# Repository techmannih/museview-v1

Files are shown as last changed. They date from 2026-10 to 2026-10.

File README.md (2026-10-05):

# MuseView V1

MuseView V1 is a compact Wi-Fi camera controller powered by standard **5 V USB-C**. It connects an **Arducam M0031 OV2640 camera** to an **ESP32-S3-WROOM-1-N16R8**, with dedicated camera power supplies, USB programming, an ASK/CAPTURE button and a status LED on a 50 × 35 mm board.

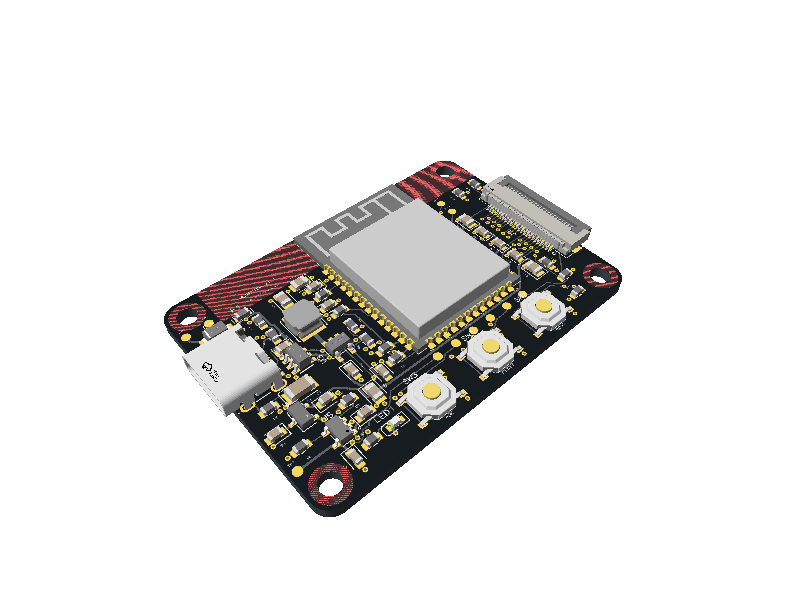
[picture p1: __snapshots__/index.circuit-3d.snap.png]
Assembled MuseView PCB


## Overview

MuseView brings the camera interface, power regulation and controls onto one board. The ESP32 module provides Wi-Fi, 16 MB flash for firmware and 8 MB PSRAM for camera buffers. The external M0031 camera connects through the 24-pin FPC connector on the right edge; the USB-C connector on the left supplies power and provides a programming/debug connection. All PCB assembly components are on the top side.

The included ESP-IDF firmware provides a local photo-capture page. A phone or computer joins the board's Wi-Fi network and opens the page in a browser. Photos can be taken from that page or with the physical ASK button, making the board a starting point for embedded camera projects and image-capture applications.

## How it works

1. **Power the board.** USB-C supplies 5 V through the input protection circuit. The regulators generate the shared 3.192 V MCU/camera I/O supply, 2.8 V camera analog supply and 1.296 V camera core supply.
2. **Initialize the camera.** After startup, the ESP32 releases the camera's power-down/reset controls, configures the OV2640 and receives image data over its 8-bit DVP interface. The supplied firmware captures JPEG images at SVGA resolution using PSRAM-backed camera buffers.
3. **Connect over Wi-Fi.** With the firmware flashed, join `MuseView-XXXXXX` using the configured Wi-Fi password, then open `http://192.168.4.1/`. The ESP32 serves the capture page directly to the connected device.
4. **Take a photo.** Click **Capture** in the browser or press **ASK/CAPTURE** on the board. The LED lights during capture. **Last ASK capture** displays the most recently cached image; the latest JPEG is kept in RAM and replaced by the next capture. Images stay on the local connection and are not stored permanently.
5. **Program or recover.** USB supports firmware flashing and serial debugging. RESET restarts the board; holding BOOT while pressing RESET enters the ESP32 ROM download mode.

See the [firmware setup guide](https://github.com/techmannih/museview-v1/blob/main/firmware/README.md) for Wi-Fi configuration, flashing and the browser interface.

## Use

```sh
bun install --frozen-lockfile
bun run verify
bun run dev
bun run build:preview
bun run build:handoff
bun run export:assembly
bun run snapshot
bun run snapshot:3d
bun run export:release
```

The library/CLI is pinned to tscircuit 0.0.2687. Builds use selected supplier numbers, not automatic part substitution. `hardware-contract.json` is checked against the generated source netlist. `scripts/check-decoupling.mjs` measures actual local copper. The strict `bun run check:schematic-style` gate runs Style Analysis 0.0.39 on all four built sheets and fails on any issue; the native CLI placement command only prints suggestions. Its dependencies are isolated while explicit pins preserve the existing PCB runtime. Placement, routing diagnostics and a separate Gerber copper short check must pass before a release can be considered.

Start the viewer with `bun run dev` (optionally `--port 3020`) after installing the locked dependencies. The launcher requires the local pinned CLI and refuses a missing or mismatched installation. A bare global `tsci dev` can load a different browser renderer and produce a stale-routing error followed by disconnected-port errors; see [viewer troubleshooting](https://github.com/techmannih/museview-v1/blob/main/docs/routing.md#viewer-troubleshooting). The separately published website renderer is supported for its reviewed mounting-keepout representation; it still rejects other stale routing inputs.

## Design

- 50 × 35 mm, 1.6 mm FR4, four copper layers, black solder mask, **all 49 fitted components on top; no bottom assembly**.
- Via minima: **0.30 mm hole / 0.45 mm pad**. Actual through vias: **0.30 mm drill / 0.60 mm pad**, with 0.15 mm annular rings.
- L1 components/signals, L2 ground reference, L3 common MCU/camera I/O power, L4 signals. Antenna keepout on all copper layers.
- USB-C USB 2.0 device: independent 5.1 kΩ CC pull-downs, USBLC6-2SC6, 33 Ω data resistors, 750 mA PTC, SMF5.0A input TVS.
- TLV62569: **3.192 V nominal** shared ESP32/camera I/O, using 432 kΩ/100 kΩ, both **0.1%**.
- XC6206P282MR: camera analog 2.8 V, supplied from protected USB 5 V to avoid marginal dropout headroom.
- SGM2059: camera core **1.296 V nominal**, using 25.5 kΩ/40.2 kΩ, both 1%. Net: **CAM_1V3**, TP7 acceptance **1.24–1.36 V**.
- Native USB ROM recovery, UART0/JTAG pads, BOOT, RESET, ASK GPIO16 and LED GPIO17.
- Camera RESET GPIO18 defaults low and PWDN GPIO8 defaults high. Firmware must actively release them.

These rail choices retain the corrected 1.296 V camera core and avoid a marginal 2.8 V camera-to-3.318 V ESP32 I/O interface. See [electrical decisions](https://github.com/techmannih/museview-v1/blob/main/docs/electrical-review.md) and the [pin contract](https://github.com/techmannih/museview-v1/blob/main/hardware-contract.json).

## Repository

The repository contains the MuseView board entrypoint, local component and CAD imports, a Bun lockfile, automated checks and schematic/PCB/3D snapshots.

```text
index.circuit.tsx             board, four schematic sheets, placement and copper
pcb-routes.json               reviewed routes, guarded by geometry/net fingerprint
routing/                     native geometry and pinned routing-generation inputs
imports/                     JLC-imported ICs/connectors/CAD; native passives
scripts/                     verification, mutation tests and exports
sourcing/                    timestamped JLCSearch evidence and alternatives
__snapshots__/               reviewed schematic, PCB and 3D renders
docs/                        assembly, electrical review, bring-up, release checks
firmware/                    matching ESP-IDF camera bring-up application
.github/workflows/           automated build/check pipeline
dist/                        generated CAD/manufacturing output (ignored)
release/                     published, versioned handoff files
```

USB-C is on the left, the camera connector is on the right, the antenna faces the top edge, and ASK / RESET / BOOT sit along the bottom edge. Bottom copper carries routing; all fitted components are on top.

## Assembly boundary

The external Arducam M0031 camera, USB cable and enclosure are not JLCPCB assembly components. JLCSearch quantities are cached catalogue evidence, not reserved stock or a confirmed assembly quotation. Recheck the selected BOM in JLC's assembly portal immediately before ordering. FPC mating, prototype rail/transient measurements, USB signal integrity and camera capture require hardware validation; successful software checks do not establish those results.

Component import/stock provenance and datasheets: [sources](https://github.com/techmannih/museview-v1/blob/main/docs/sources.md). Current validation and open physical checks: [release checks](https://github.com/techmannih/museview-v1/blob/main/docs/release-checks.md).

View the four schematic sheets: [USB](https://github.com/techmannih/museview-v1/blob/main/release/schematic-usb.svg), [power](https://github.com/techmannih/museview-v1/blob/main/release/schematic-power.svg), [MCU](https://github.com/techmannih/museview-v1/blob/main/release/schematic-mcu.svg), [camera](https://github.com/techmannih/museview-v1/blob/main/release/schematic-camera.svg). Board views: [top](https://github.com/techmannih/museview-v1/blob/main/release/pcb-top.svg), [bottom](https://github.com/techmannih/museview-v1/blob/main/release/pcb-bottom.svg). Editable manufacturing/CAD exports: [Gerbers](https://github.com/techmannih/museview-v1/blob/main/release/museview-v1-gerbers.zip), [KiCad](https://github.com/techmannih/museview-v1/blob/main/release/museview-v1-kicad.zip), [STEP ZIP](https://github.com/techmannih/museview-v1/blob/main/release/museview-v1-step.zip), [GLB](https://github.com/techmannih/museview-v1/blob/main/release/museview-v1.glb). See [routing workflow](https://github.com/techmannih/museview-v1/blob/main/docs/routing.md) before changing placement or nets.

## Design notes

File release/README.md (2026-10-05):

# MuseView V1 manufacturing handoff

**ORDER HOLD:** this package corrects the camera core to CAM_1V3, 1.296 V nominal (R8 25.5 kΩ / R9 40.2 kΩ). The previous 1.197 V package is superseded. Exact M0031 flex qualification and physical bring-up remain open; see `../docs/camera-mating.md`.

- `museview-v1-gerbers.zip`: four copper layers, solder masks/paste, silkscreen, outline, plated L1–L4 drills (all vias 0.30 mm drill / 0.60 mm pad) and nonplated drills. Generic exporter BOM/CPL are removed to avoid competing assembly files.
- `jlc-bom.csv` and `jlc-cpl.csv`: the authoritative 49-component **top-only** assembly pair. No bottom-side components. Board-center origin matches the Gerbers. Validate polarized-part rotations in JLC's placement preview.
- `schematic-usb.svg`, `schematic-power.svg`, `schematic-mcu.svg`, `schematic-camera.svg`: four readable vector schematic sheets.
- `pcb-top.svg`, `pcb-bottom.svg`, `pcb-top.png`: copper/placement views.
- `museview-v1-kicad.zip`: PCB, project, root plus four schematic sheets and 16 model files. Extract the whole archive; retain its `3dmodels/` tree.
- `museview-v1-step.zip` (extract `museview-v1.step`), `museview-v1.glb`, `3d.png`: assembled mechanical model, portable textured 3D model and preview. Camera is an external assembly item. The STEP is zipped because the cloud importer exceeds its 32 MiB RPC limit when copying the loose assembled model; component STEP/OBJ files are retained for rendering.
- `circuit.json`: exact verified tscircuit interchange/netlist/geometry; CAD URLs resolve relative to repository root.
- `camera-supply.json`: divider identities, tolerances, calculated DC/temperature bounds and 1.24–1.36 V limits.
- `verification.json`, `sha256.json`: verification evidence and artifact checksums.

J1 uses the supplied USB-C CAD origin correction: local Y = -2.3500289000000517 mm. The browser preview, GLB, KiCad model offset and assembled STEP all use this origin. The pinned STEP exporter otherwise recentres the model and ignores its explicit origin, so `scripts/align-usb-step.mjs` corrects only J1's mapped placement after export; handoff validation checks that placement. The footprint, BOM/CPL and routed copper are unchanged.

USB-C is 5 V only. Use the assembly, electrical review and bring-up documents in `../docs/`. Physical power/startup/USB/camera tests and manufacturer stackup/impedance review remain open. This package is an engineering prototype handoff, not a claim of measured production qualification.

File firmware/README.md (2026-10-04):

# Hardware bring-up firmware

ESP-IDF 5.4.x, target ESP32-S3, espressif/esp32-camera 2.1.8. Uses octal 8 MB PSRAM and 16 MB flash. The pin header is generated from `hardware-contract.json` by `bun run generate:firmware-pins`; the verification task rejects stale mappings.

```sh
cd firmware
idf.py set-target esp32s3
idf.py menuconfig
idf.py build
idf.py -p YOUR_PORT flash monitor
```

Set a unique local Wi-Fi password in the MuseView menu (at least 8 characters). After flashing, connect a phone to `MuseView-XXXXXX` using that password; the development default is `museview-setup`. Open http://192.168.4.1/ to capture a JPEG. ASK captures a fresh frame and updates the last-image endpoint; LED lights during capture. No camera image is sent to an external service. This AP is a bring-up interface, not production provisioning or an Internet API.

The application checks PSRAM, initializes the OV2640 in JPEG SVGA mode, and serializes camera access between HTTP and the debounced ASK task. Captured frames are copied to PSRAM-backed memory before returning the driver's frame buffer. HTTP returns an error when no frame is available. Maximum cached JPEG is 1 MiB. There is no SD card or persistent image storage.

Native USB ROM recovery remains available by holding BOOT during RESET. This firmware provides USB Serial/JTAG console, not UVC webcam firmware. Electrical operation and images are untested until the physical board is assembled.

The corrected camera core is CAM_1V3, 1.296 V nominal from the hardware divider. The generated header carries a 1296 mV target and 1240–1360 mV acceptance limits; the boot log reports these as external measurement requirements. There is no ADC connection to this rail, so firmware neither programs nor validates its voltage. GPIO assignments remain unchanged.

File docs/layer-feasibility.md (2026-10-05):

# Two-layer feasibility review — 2026-10-05

**Decision: retain the existing four-layer release. The tested two-layer draft is NOT READY and must not be ordered. Four layers are recommended, not mandatory for an ESP32-S3 design.**

Espressif's [PCB layout guidelines](https://docs.espressif.com/projects/esp-hardware-design-guidelines/en/latest/esp32s3/pcb-layout-design.html) explicitly permit two layers, while recommending four. They call for minimal bottom-layer routing and continuous ground in a two-layer implementation, and a continuous reference beneath USB differential routing. MuseView uses the WROOM module; bare-chip RF, crystal and memory layout requirements must not all be interpreted as baseboard requirements.

## What was tested

The isolated trial started from commit `7c9b41137d943b7360f18bac38ae7db58a59127b`. It retained the 50 × 35 mm outline, existing assembly-part positions, top-only assembly, USB-C 5 V without PD, ESP32-S3-WROOM-1-N16R8, M0031 and the existing supply targets. The declared via minima remained 0.30 mm drill / 0.45 mm pad; actual vias retained 0.30 mm drills / 0.60 mm pads.

The trial removed the inner planes, routed supply connections on the outer layers, added top/bottom GND pours and additional ground stitches, and tried several route orders and local ground connections. It was a real two-layer routing experiment, not merely a change to the board's layer count. Existing release checks were not disabled to accept it.

## Result

| Check | Latest trial result |
| --- | --- |
| Board copper layers | 2 |
| Grid-router failed connections | 0; 120 generated traces |
| Complete circuit geometry | 169 PCB traces, 143 vias |
| Native circuit build | Failed: 23 `pcb_port_not_connected_error` diagnostics on GND |
| Independent ground-polygon analysis | Three disconnected ground groups |
| Manufacturing export | Not performed; draft rejected before release |

The ground groups are the main board ground, a separate island containing **C13.pin2 and C16.pin2**, and another containing **J2.DGND**. The 23 diagnostics are not 23 separate islands: the checker reports multiple members of the incompletely connected net. Zero router failures therefore does not establish complete PCB connectivity.

A second diagnostic sampled USB centerlines at intervals no greater than 0.05 mm against opposite-layer GND pours and pads. It found uncovered runs up to approximately **3.69 mm on the D− port/ESD network** and **2.96 mm on D+**. This includes connector and IC escapes. It is a geometric reference-coverage check, not an impedance calculation or a physical USB test. PORT/ESD aliases refer to the same connected copper and must not be summed as independent measurements. Ground traces and vias are not counted as a reference plane by this diagnostic.

The machine-readable [trial evidence](evidence/two-layer-feasibility.json) records the draft hashes, diagnostics, ground groups and sampling results. The rejected draft and its detailed logs are retained separately in the local feasibility workspace; they are not release inputs.

## Consequence

This experiment does not prove that a two-layer MuseView is impossible. It shows that the tested conversion of the current placement does not meet connectivity and return-path requirements. A two-layer version needs further placement/routing work around the camera grounds, power distribution and USB, followed by complete verification and new manufacturing exports. A smaller layer count alone is not a safe cost reduction.

The committed PCB, routing, BOM/CPL, Gerbers and CAD remain the existing four-layer design. Its inner GND and VDD_IO planes are electrically active and cannot simply be deleted. The existing M0031/AFC01 mechanical qualification and JLC placement-preview items remain open; this layer review does not close them or authorize an order.

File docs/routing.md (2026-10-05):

# Routing and reproducibility

V1.1 uses a 50 × 35 mm outline. The source circuit, local bypasses, FPC fanout, copper planes and RF exclusion are defined in `index.circuit.tsx`. All assembly is on top. Signal routing uses the two outer copper layers; L2 is GND and L3 is VDD_IO.

The remaining copper is generated by `scripts/route-grid.py` on a 0.05 mm grid from tscircuit's exported geometry. USB data contacts escape under the receptacle; active ESP32 signal pads escape toward the free area under the module. Local ground and I/O supply spurs terminate directly on their planes. All fixed and generated vias use 0.30 mm drills and 0.60 mm copper pads (0.15 mm annular rings). The board declares `minViaHoleDiameter={0.3}` and `minViaPadDiameter={0.45}`. The pad minimum is a lower bound; `pcbStyle` and the explicit vias retain actual 0.60 mm pads. The generator reads the captured minima and selects a pad of at least drill + 0.30 mm, preserving the 0.15 mm annular ring and reserving its full clearance. Feedback traces are routed before plane drops, with JTAG_TDO routed after the camera bus to keep the larger via escapes clear. C4's ground via is at (-13, 10.1) mm to clear its pad and the antenna exclusion. The router checks expanded pad, fixed-track, via, hole, RF and board-edge obstacles, then joins each remaining net.

`routing/input.simple-route.json` is the exact native routing input. `routing/geometry.json` contains the source/port/placement records needed by this board-specific generator, including the explicit USB ESD bypass and 39 fixed vias. These are regeneration inputs, not manufacturing files. Python 3.11+ and the pinned NumPy package in `routing/requirements.txt` are needed only to regenerate routing. Bun builds replay the checked copper without Python.

```sh
python3 -m venv .venv
.venv/bin/pip install -r routing/requirements.txt
bun run capture:routing
PYTHON=.venv/bin/python bun run regenerate:routing
bun run verify
```

The generator refuses to replace `pcb-routes.json` if any connection fails. `scripts/board-router.ts` then replays that copper only when the geometry/net fingerprint matches the current tscircuit input. Native DRC, exact endpoint checks and the separate Gerber short analysis still run. GitHub CI regenerates the copper, checks that the saved file matches, and runs the full verification suite.

When changing electrical values, nets or placement, run `bun run capture:routing` to capture native prerouting geometry from the current JSX source. This uses an empty capture-only router and never exports that unrouted intermediate as manufacturing output. Regenerate the grid copper and run the full verification suite next. The fingerprint now includes the hardware contract, so divider-value or power-net changes also invalidate replay even if physical coordinates are unchanged. Ordinary schematic display-text edits remain excluded. Never copy a fingerprint onto stale routes.

After verification, update and compare the 2D and 3D snapshots and run `bun run export:release`. All exported drills are through plated L1–L4 or nonplated. There are no blind/buried drills. The bottom stencil is intentionally empty; bottom copper is routing, with no fitted components. Recheck JLC rotations, stackup and physical USB/camera operation before production.

The snapshot tool's optional selector route-cache writer may warn that a via selector is ambiguous. That secondary cache is not used; the explicit geometry-guarded route file supplies the copper.

## Viewer troubleshooting

The 2026-10-04 report of 137 errors came from a checkout without local dependencies, running global tscircuit 0.0.2308. Its browser renderer rejected the saved routing fingerprint; the 134 disconnected ports and two missing traces followed from that rejection. Use the locked tscircuit 0.0.2687 installation with `bun run dev`, stop the old server, and reload the browser. The launcher now checks the installed version before starting the local CLI. Do not remove the fingerprint guard or copy an expected hash over stale copper.

The pinned viewer also runs supplier orientation analysis. This exposed D1's unused pin-label map: native numbering put the anode at pin 1, while C193402 numbers the cathode as pin 1. The import now explicitly maps pin 1/cathode to the west VBUS_5V pad and pin 2/anode to the east GND pad. The electrical contract and a regression test enforce this. The TVS symbol is imported from `imports/SMF5_0A/TVSSymbol.tsx`, with explicit cathode/anode ports and drawing paths. Its upper cathode bar connects to VBUS_5V; its lower anode connects to GND. Native routing inputs and route endpoints were regenerated for the corrected port identities; physical pad positions, net geometry, component rotations and copper paths are unchanged. JLC's actual assembly placement preview remains pending.

### Missing TVS symbol

The published v0.1.11 viewer displayed `Symbol not found: avalanche_diode_sm_up`, although the pinned local renderer could draw it and the cloud build passed. Build success did not establish viewer symbol compatibility. D1 now imports a self-contained unidirectional TVS symbol instead of requesting that catalog entry. The drawing, labels and numbered ports are included in circuit JSON, keeping C193402 pin 1 as the cathode. This is a schematic-only change.

`bun run check:schematic-render` renders every sheet, rejects missing-symbol diagnostics and verifies the embedded TVS cathode bar, triangle and both leads. It runs in verification and release export; regression tests also reject reverting D1 to the catalog-only symbol. The published viewer must still be inspected after deployment because its renderer is versioned independently.

### Published tscircuit.com renderer

The hosted compatibility capture was repeated on 2026-10-05 after the 0.30 mm via reroute. Its complete routing-input fingerprint is `904ff28e-139073e2-1060756`, versus the pinned input `c6bc715a-6984f1ee-1060756`. Capturing the same source with tscircuit 0.0.2744 / core 0.0.2079 showed exactly four changes: obstacles 257–260 use `type: rect` instead of `type: oval`. These are the four unconnected, all-layer mounting-hole keepouts, each 4.6 × 4.6 mm at (±22.25, ±14.75). Core 0.0.2021 emitted ovals; the newer core emits their bounding rectangles.

The grid router uses these rectangular bounds. Both runtime captures describe the same current placement, nets and regenerated copper. `board-router.ts` accepts this one reviewed **complete input fingerprint**, only when the saved routing still has its corresponding original fingerprint. No shapes, dimensions, nets or other fields are removed from fingerprinting. Every other input continues to fail closed. The added replay tests check identical returned copper for both captures and rejection of moved/resized keepouts, changed layers, changed pad shapes and changed nets.

This compatibility entry is specific to this routing revision. A future renderer or design change needs a fresh capture, full input comparison and verification; do not add its hash merely to dismiss the error. Use the pinned release pipeline for fabrication exports. Website edits must also be saved/published: pushing GitHub alone does not update a separately published registry release.

### Cloud sandbox file-size failure

Release v0.1.5 failed before circuit compilation while copying repository files into the cloud sandbox. The [build log](https://tscircuit.com/techmannih/museview/releases/a095f8d4-827e-4740-89f3-d1a58d011f7a) reports a 46,622,166-byte serialized RPC payload against a 32 MiB limit. The next input after the successfully copied GLB was the 23,312,026-byte assembled `release/museview-v1.step`.

The assembled model is now distributed as `release/museview-v1-step.zip`; extracting it restores the full STEP. The [GitHub importer filter](https://github.com/tscircuit/api.tscircuit.com/blob/01251be3e667f5f4b03e488bc4ed214bf7caec4f/lib/github/file-filter.ts) skips ZIP files, so the large handoff artifact is not a cloud build input. Individual component STEP/OBJ assets under `imports/` remain in the package. `export:release` generates the loose assembled STEP under ignored `dist/release/` before packaging it; `check-handoff.mjs` validates the archive and rejects loose release STEP files.

`ignoredFiles: ["release/**", ...]` also prevents generated handoff files from entering the local dev file server. This setting alone does not fix GitHub cloud imports, which use their own fixed filter. A new GitHub sync/release is needed; retrying the already-copied v0.1.5 file set will repeat the failure. No electrical, routing, schematic or 3D geometry changes are part of this packaging fix.

## Layer review, 2026-10-05

Four layers are retained for this revision. The inner layers are active: the regenerated routing includes 25 top-to-GND-plane and 16 top-to-VDD_IO-plane transitions, in addition to explicitly placed bypass/ground vias. All 176 via barrels span L1–L4; a route transition to an inner plane does not denote a blind via. The outer signal routing includes 841 bottom-layer wire points. Removing the inner copper would disconnect the current power/ground distribution and change its return paths.

A two-layer ESP32-S3 design is possible in principle. Espressif's [PCB layout guidelines](https://docs.espressif.com/projects/esp-hardware-design-guidelines/en/latest/esp32s3/pcb-layout-design.html) recommend four layers, and describe two layers with minimal bottom routing and a continuous ground plane. This board uses a WROOM module, so chip-level RF layout rules are not all baseboard requirements. The present dense baseboard does use its planes; a two-layer version needs rerouted power, a reviewed ground pour and USB return paths. No two-layer layout has been qualified in this revision. This assessment preserves the existing 50 × 35 mm component placement rather than claiming four layers are mandatory for every implementation.

An [isolated two-layer routing trial](layer-feasibility.md) subsequently completed the generated routes but failed native ground connectivity checks. Polygon analysis found separate C13/C16 and J2.DGND ground islands, and USB reference-coverage sampling found gaps. That draft was rejected before manufacturing export; the four-layer source and release artifacts remain unchanged.

J1 now uses tscircuit's native `standard="usb_c"` schematic, with grouped VBUS/CC/data/GND pins and S1–S4 shield tabs below. Supplier pad numbering is retained: pins 7/9 are D− and 8/10 are D+. The contract rejects changes to that mapping. Its exact footprint and user-supplied CAD alignment are unchanged.

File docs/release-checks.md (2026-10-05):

# Release checks

Status: **NOT READY** for the first prototype. Only the two pre-order items below remain open; post-assembly measurements are listed separately. The machine-readable [`verification.json`](../release/verification.json) records the exact circuit hash and check outcomes. Manufacturing exports are versioned in `release/`, with SHA-256 hashes.

Local verification completed on 2026-10-05: source netlist, schematic placement, strict all-sheet Style Analysis, PCB placement, routing difficulty, board build, electrical contract, actual copper continuity, local bypasses, exact M0031 supply bounds, assembly/stock checks and separate Gerber short analysis passed. Twenty-nine regression tests passed, including supplier TVS pin polarity, the two captured renderer inputs and rejection of schematic style regressions. Native 2D and 3D snapshot regeneration/compare runs matched. The GitHub workflow repeats the circuit checks and 2D snapshots and compiles the matching ESP-IDF 5.4.2 firmware.

The 0.30 mm drill / 0.60 mm via pad revision includes regenerated routing, a native standard USB-C schematic and exact supplier pin-mapping checks. Four active copper layers are retained; see `routing.md` for the layer assessment. D1 imports the self-contained TVS drawing with its cathode bar toward VBUS_5V. All four sheets pass the pinned Style Analysis and missing-symbol rendering checks. No issue filters or disabled checks are used. The current routing fingerprint and drill tools are recorded in `release/verification.json`.

Exact trace/via counts are recorded in `verification.json`. There are zero build/routing errors and zero detected Gerber shorts. The retained native width warnings are explained in `electrical-review.md`; critical local widths are checked against their exact endpoints. All 28 selected assembly part numbers had positive JLCSearch stock in the dated evidence. This is availability evidence, not a PCBA order acceptance.

The handoff exporter verifies five KiCad schematic files (root plus four children) and all 16 distinct native/imported STEP models. GLB embeds the local OBJ bodies. KiCad files are interchange exports; no native KiCad ERC/DRC run is claimed. The tscircuit source and its checked copper remain authoritative.

| Check | Evidence required |
|---|---|
| Electrical contract | `bun run check:contract`, matches generated netlist |
| Stock | `sourcing/bom-with-stock.csv`, timestamped JLCSearch URLs |
| Type and source netlist | `bun run typecheck`, `tsci check netlist` |
| Placement and schematic | Native checks, strict `check:schematic-style` with zero issues, plus reviewed four-sheet renders |
| PCB | Zero build errors, connectivity checks, zero Gerber shorts |
| Bypass loops | `bun run check:decoupling`, actual local copper length |
| Assembly | Exact part identities, all fitted parts top, FPC pitch, JLC placement review |
| Firmware | CI compile and generated pin header consistency; physical operation separately |
| Fabrication | Review Gerber/drill/stackup/impedance with manufacturer |
| Hardware | Rails, startup, thermal/current/USB/camera tests in `bring-up.md` |

First-prototype blockers:

1. **Exact M0031-to-J2 mating qualification** — AFC01 requires a tighter 0.29–0.31 mm tail than F32R’s 0.27–0.33 mm range. Exact seating/latch fit remains unqualified. The numbered-tail photo also raises a possible reversed camera-to-J2 mapping after accounting for contact face and insertion direction; the current one-to-one numbering is not physically signed off. See `camera-mating.md`.
2. **JLC assembly placement approval** — the exported rotations are CAD angles. Verify U1/J1/J2/D1/LED1/U2/U3/U4/U5 alignment and centroids in the authenticated JLC preview, using `placement-review.md` and the generated `release/placement-review.json`. The Gerber upload was recognized as 4 layers, 50 × 35 mm. No order/payment was submitted.

After assembly: no physical PCB has been tested in this task. Source-current/inrush, rails/ripple/thermal behavior, USB enumeration and camera capture are prototype bring-up work before production. They are not circular prerequisites for ordering the first prototype. Manufacturing stackup and assembly eligibility must still match the actual quote; automated checks do not replace manufacturer review.

The 1.197 V camera-core revision is superseded. R8 = 25.5 kΩ and CAM_1V3 are mandatory. Electrical checks validate the declared board nets, including J2 pin 10 to CAM_1V3; they cannot prove the camera-to-connector contact mapping. See `camera-mating.md` for the tolerance comparison and possible numbering reversal. Neither exact tail qualification nor the numbered physical mating has been signed off.

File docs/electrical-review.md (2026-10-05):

# Electrical decisions

## Standard USB-C

The final user clarification specifies standard 5 V USB-C, overriding the initial request for PD. J1 CC1 and CC2 each have their own 5.1 kΩ resistor to ground. There is no controller or higher-voltage negotiation. Both receptacle D+ contacts and both D− contacts are connected for reversible insertion. USBLC6's physical 1/6 and 3/4 pass-through pairs are represented as internally connected pins. GPIO19 is D− and GPIO20 D+.

A 750 mA resettable fuse is a thermal protective element, not an accurate current limiter. The board has no CC-current measurement or programmable input-current limit. Use a regulated 5 V source rated at least 1 A for bring-up. Compatibility with every USB host's pre-enumeration current budget and inrush limit is **not established**. Do not label the product USB-IF certified. The 5 V TVS provides transient suppression; it cannot protect the 5.5 V-maximum buck against sustained overvoltage.

## Voltage domains

The exact Arducam M0031 product specifies a 1.3 V ±5% core supply. OmniVision OV2640 datasheet v2.2, table 6, narrows this to 1.24–1.36 V. The earlier v1.6-based 1.197 V design was incorrect for this module and is superseded. The selected SGM2059 divider is now R8 = 25.5 kΩ (C22920, 0603WAF2552T5E) and R9 = 40.2 kΩ (C2933218, FRC0603F4022TS), both 0603, 1%, 100 ppm/°C. Exact JLCSearch identities and positive quantities were refreshed on 2026-10-04. The implementation uses:

| Rail | Equation | Nominal | DC tolerance estimate |
|---|---|---:|---:|
| MCU + camera DOVDD | 0.600 × (1 + 432k / 100k) | 3.192 V | 3.123–3.261 V, VFB ±2%, resistors ±0.1% |
| Camera DVDD | 0.793 × (1 + 25.5k / 40.2k) | 1.296 V | 1.254–1.339 V, VFB 0.773–0.813 V, resistors ±1% |
| Camera AVDD | XC6206P282MR | 2.800 V | ±2% initial, before line/load/temp effects |

The camera divider produces 1.296022 V nominal. Using the SGM2059 full-temperature feedback limits 0.773–0.813 V and initial 1% resistor tolerances gives 1.253626–1.339127 V. Including independent worst-direction 100 ppm/°C drift over the sensor DC table’s −30 to +70°C range (55°C maximum excursion from 25°C) gives 1.248367–1.344948 V. This leaves approximately 8.37 mV of lower-bound and 15.05 mV of upper-bound margin before ripple, transients and measurement uncertainty. `check:camera-supply` computes these bounds from actual generated resistor values and exact stocked-part metadata. These temperature assumptions are a calculation boundary, not an assembled-board operating-temperature rating.

The first two ranges are worst-case DC divider calculations, **not measured regulation guarantees** including ripple and transient droop. Both R6 and R7 need 0.1% tolerance; substituting the original 1% feedback parts defeats the I/O voltage margin. Camera SDA/SCL pull-ups, reset/power-down control and pixel data use the same nominal rail as the ESP32. Confirm actual sensor VOH/VIH and output loading on the purchased M0031 revision.

U4's input is the protected 5 V rail. A 3.192 V input would leave too little worst-case dropout margin at 2.8 V. At 50 mA analog load U4 dissipates approximately (5−2.8) × 0.05 = 0.11 W. U5 is fed from VDD_IO; at 100 mA it dissipates approximately 0.19 W. These are load scenarios, not measured loads. Verify thermals and camera rail current; there is no established full-temperature operating rating for this assembled board.

## Reset and startup

ESP EN uses 10 kΩ and 1 µF. Camera RESET is held low by 10 kΩ, while PWDN is held high by 10 kΩ. Firmware first drives those states, waits for rails, then releases PWDN and RESET before driver initialization. This does not independently enforce the sensor's rail sequencing; verify rail rise/fall waveforms against the exact sensor specification, especially on unplug/replug. GPIO0 retains a BOOT pull-up; GPIO35/36/37 are reserved for octal PSRAM and unused.

## Local routing

Critical regulator input capacitors and the ESP32 HF capacitor have explicit top copper and nearby ground vias. Scripts verify actual lengths: regulator/MCU supply bypass ≤3 mm, USB ESD supply bypass 3.774 mm (≤4 mm) and local capacitor-to-ground-via ≤1.6 mm. The TLV62569 switch connection is ≤3 mm. Camera C13/C14 supply bypasses are each about 4.70 mm (both top-only, no vias); regression checks enforce 5.1 mm maximum and those via budgets. C15 and J2 DOVDD have ≤1.6 mm local spurs to the common inner I/O plane. The library's generic capacitor limit applies to arbitrary power-net branches; `imports/passives.tsx` therefore sets a distribution-branch limit while the stricter local checks operate on the actual intended endpoints.

Four-layer pours preserve the ground reference and antenna exclusion. Fabricator stackup, dielectric thickness, USB differential impedance/skew and return continuity must be reviewed with the exported copper; a nominal track width alone does not establish 90 Ω differential impedance. The board runs ESP32-S3 USB full speed, not high speed. Camera XCLK/PCLK edge quality and timing must be measured with the selected flex cable.

## Scope

The firmware supports camera capture and hardware bring-up. Physical validation covers the power rails, startup behavior, USB operation and camera interface; see `bring-up.md` for the measurement procedure.

The pinned native trace-width checker emits net-wide width warnings because it compares each requested local trace width with every branch on the same electrical net. The dedicated endpoint/width/length checks independently enforce the critical local widths, including 0.2 mm post-ESD USB segments (the connector fanout is 0.15 mm); these warnings are retained in the exported circuit JSON. No routing, connectivity, placement or Gerber short error is waived.

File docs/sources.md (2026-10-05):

# Component sources and datasheets

Checked 2026-10-04. JLC evidence includes exact fetch timestamps and URLs in `sourcing/stock-snapshot.json`. Stock is a cached search snapshot, not a reserved quantity.

- ESP32 module: https://documentation.espressif.com/esp32-s3-wroom-1_wroom-1u_datasheet_en.pdf
- ESP32 hardware guidance: https://docs.espressif.com/projects/esp-hardware-design-guidelines/en/latest/esp32s3/pcb-layout-design.html
- TLV62569: https://www.ti.com/lit/ds/symlink/tlv62569.pdf
- XC6206: https://product.torexsemi.com/system/files/series/xc6206.pdf
- SGM2059: https://www.sg-micro.com/rect/assets/c90e4805-a9a9-4001-be72-fb96737d867e/SGM2059.pdf
- USBLC6-2: https://www.st.com/resource/en/datasheet/usblc6-2.pdf
- OV2640 manufacturer datasheet v2.2, table 6, hosted by Robu: https://robu.in/wp-content/uploads/2024/09/OV2640_DS.pdf
- Exact Arducam M0031 product/core/mating connector: https://www.arducam.com/arducam-ov2640-camera-module-2mp-mini-ccm-compact-camera-modules-compatible-with-arduino_m0031esp32-esp8266-development-board-with-dvp-24-pin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
- Amphenol F32R recommended mate: https://www.amphenol-cs.com/product/f32r1a7h111024.html
- Amphenol F32R bottom-contact/0.30 mm interface: https://cdn.amphenol-cs.com/media/wysiwyg/files/documentation/datasheet/flex/ffc_fpc_050mm_f32r_f32q.pdf
- Amphenol F32R/F32J dimensioned drawing A-S0201 rev C, visually inspected: https://cdn.amphenol-cs.com/media/wysiwyg/files/drawing/f32r-f32j.pdf (SHA-256 `ccb80cfe928b3ab5cb602e74da5e3fe788bbf19c41fc63e2e992ffa461303bb0`)
- Amphenol F32R thickness tolerance, specification IS.EQC.001 rev D: https://cdn.amphenol-cs.com/media/wysiwyg/files/documentation/f31q-f32r-f52q-f52r_prodspec.pdf (manufacturer PDF downloaded via https://mm.digikey.com/Volume0/opasdata/d220001/medias/docus/6256/f31q-f32r-f52q-f52r_prodspec.pdf ; SHA-256 `c78407cb7ef80c4142c3566afae8f0222eef4fee88663f247b355b14d4eee4a7`)
- JUSHUO AFC01 drawing/specification, C262669: https://datasheet.lcsc.com/datasheet/pdf/97e3ba016a78286ffa6cfbc591e2beb6.pdf
- M0031/pinout: https://blog.arducam.com/ov2640-vs-ov7670-detailed-comparisons-and-resources/
- JLCSearch: https://jlcsearch.tscircuit.com/

Native resistors/capacitors use explicit JLC numbers rather than an automatic parts engine. Other parts and local STEP/OBJ bodies were obtained through tscircuit's JLC import flow. Supplier CAD/symbol data remain subject to their original terms; no blanket relicensing of vendor assets is asserted.

The power and interface design uses a common 3.192 V MCU/camera I/O supply, 1.296 V camera core, 0.1% main feedback resistors, 5 V analog-LDO input, controllable camera reset/powerdown, camera I/O decoupling and local ESD-supply bypass. USB-C supplies standard 5 V power.

Supplier STEP entity terminators were normalized from `) ;` to `);` for the pinned exporter’s parser. Geometry/entity arguments were not changed. `bun run normalize:step` reproduces this formatting operation after a fresh import. Assembled STEP export then completes without omitted-model warnings.

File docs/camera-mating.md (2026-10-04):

# Exact M0031 camera mating review

Reviewed 2026-10-04 against both manufacturer drawings and the user-supplied numbered-tail photograph. **NOT READY: nominal interface compatibility is supported, but full AFC01 equivalence and the camera-to-board numbering are not qualified.**

The [Arducam M0031 product page](https://www.arducam.com/arducam-ov2640-camera-module-2mp-mini-ccm-compact-camera-modules-compatible-with-arduino_m0031esp32-esp8266-development-board-with-dvp-24-pin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) explicitly names **F32R-1A7H1-11024** as its mating connector. It specifies a 24-contact goldenfinger interface and 21 × 12.5 × 5.85 mm overall module size. Overall module dimensions are not a dimensioned or toleranced tail drawing.

## Manufacturer drawing comparison

Sources: [Amphenol exact-part page](https://www.amphenol-cs.com/product/f32r1a7h111024.html), [Amphenol customer drawing A-S0201, revision C, 2019-01-28](https://cdn.amphenol-cs.com/media/wysiwyg/files/drawing/f32r-f32j.pdf), [Amphenol specification IS.EQC.001, revision D, page 1](https://cdn.amphenol-cs.com/media/wysiwyg/files/documentation/f31q-f32r-f52q-f52r_prodspec.pdf), and [JUSHUO AFC01 drawing, revision A, 2024-05-18, PDF page 2](https://datasheet.lcsc.com/datasheet/pdf/97e3ba016a78286ffa6cfbc591e2beb6.pdf). These were visually inspected; dimensions below refer to the recommended mating **FPC**, not the PCB solder lands.

| Mating feature | F32R-1A7H1-11024 | AFC01-S24FCA-00 / C262669 | Assessment |
|---|---|---|---|
| Positions / contact side | 24 / bottom | 24 / lower (F) | Match |
| Tail pitch | 0.50 ±0.03 mm | 0.50 ±0.03 mm | Match |
| Reinforced tail thickness | **0.30 ±0.03 mm** | **0.30 ±0.01 mm** | AFC01 accepts a narrower specified range |
| Tail width, 24 positions | 12.50 ±0.05 mm (W = P × (N+1)) | 12.50 ±0.05 mm | Match |
| First-to-last contact centre span | 11.50 ±0.05 mm (B) | 11.50 ±0.03 mm | AFC01 tolerance is tighter |
| FPC contact width | 0.35 ±0.03 mm | 0.35 ±0.03 mm | Match; do not use Amphenol's separate 0.30 mm FFC column |
| Exposed contact length | 3.00 mm minimum | 3.0 mm minimum | Same minimum |
| Reinforced length callout | 6.00 mm reference | 6.0 mm | Similar nominal geometry; not an exact M0031 measurement |
| Lead-in corner callout | Two R0.30, FPC only | R0.20 | Different; no measured M0031 corner profile |
| Actuator | Push/pull slider | Flip latch, illustrated open at 90° | Different actuation and retention geometry |

The F32R accepts 0.27–0.33 mm tail thickness, while the AFC01 drawing recommends 0.29–0.31 mm. A tail satisfying F32R's limits can fall outside AFC01's limits. This **does not prove that the actual M0031 is incompatible**; it proves that the named-mate evidence alone does not guarantee AFC01 compatibility. The centre-span tolerance also narrows from ±0.05 to ±0.03 mm.

Both drawings require at least 3 mm exposed contact length. That is not a universal 3 mm insertion-depth instruction: the internal contact/stop/actuator datums differ. Do not interpret unrelated housing dimensions or a photograph's pixels as insertion depth. Full seating, contact overlap and latch retention still need an exact tail drawing or a fit record. The connectors are not PCB-footprint substitutes (for example, the 24-position body-width dimensions are 16.80 mm for F32R and 16.40 mm for AFC01).

## Numbering and insertion orientation

Current board facts from the imported footprint and released circuit: J2 is on **top**, rotated 90°, mouth facing east/right, signal solder row west of the body. Board pad 1 is at the south end, **(21.1999, −7.2498) mm**; pad 24 is north. For a bottom-contact connector, insert from east toward west with exposed contacts **down toward the PCB**. “Bottom contact” does not mean bottom-side component assembly.

The user's Screenshot 2026-10-04 at 18.29.46.png shows the tail tip downward, with **24 on the left and 01 on the right**. This identifies the numbered edges in that photograph. It does not establish tail thickness, lot/revision, whether the photograph is mirrored, or physically verified latch fit.

**Do not sign off one-to-one camera/connector numbering from the labels alone.** JUSHUO's recommended-tail drawing has the insertion tip upward and circuit 1 on the right; rotated to a tip-down view, circuit 1 is on the left. If the supplied M0031 photograph is an unmirrored view of the exposed-contact face, rotating/flipping that tail into the required east-to-west, contacts-down orientation places its **01 edge north**, opposite current board pad 1 south. This is a **possible reversed pin mapping**, not a confirmed physical measurement. Resolve the photographed face and numbered-edge correlation using an exact Arducam tail/pin drawing or an unpowered sample continuity/fit record. Do not reverse the live flex, infer orientation from the lens, or silently renumber the board based only on a product photograph.

[Arducam's interface table](https://blog.arducam.com/ov2640-vs-ov7670-detailed-comparisons-and-resources/) gives camera pin 2 AGND, 4 analog, 10 core, 11 I/O and 15 DGND. The current hardware contract connects identically numbered J2 pads to these signals, with pins 1, 23 and 24 unused. Automated contract checks verify those **declared board connections**; they do not independently prove which camera contact physically touches each pad. If reverse mating is confirmed, correct the connector-to-camera mapping and rerun routing, contract, firmware-pin and complete release checks before ordering.

## Exact remaining qualification

The user confirmed that no exact M0031 revision drawing or physical sample measurements are available. Keep M0031_J2_MATING open until evidence establishes:

1. Actual reinforced tail within **0.29–0.31 mm**, with width, pitch, centre span, contact length and lead-in geometry acceptable to AFC01.
2. Exposed face and camera contact numbers correlated to **physical J2 pads**, explicitly resolving the photo's possible reversal; include unpowered checks of grounds and supply contacts.
3. Full seating, sufficient contact overlap, closed-latch retention without force, and flex/enclosure clearance.

No PCB, component, supply, routing or CPL changes were made for this evidence review. USB-C remains 5 V only; VDD_IO ≈3.192 V, CAM_2V8 =2.8 V and CAM_1V3 ≈1.296 V. JLC's authenticated placement preview is a separate open pre-order item. Rail and capture measurements after assembly remain in bring-up.md.

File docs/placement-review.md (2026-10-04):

# First-prototype assembly placement review

Reviewed 2026-10-04 against the generated board and exported CPL. **Board-side orientation landmarks checked; JLC-specific placement approval is pending.** The user chose to continue offline after the JLC login gate. No BOM/CPL placement preview, order or payment was completed.

JLC successfully detected the uploaded Gerbers as four copper layers and 50 × 35 mm. This validates file recognition only. It does not validate component matching, rotations, centroids, stackup choices or assembly eligibility. The temporary quote defaults were not approved manufacturing settings.

The table uses the top view: north is +Y, east is +X, and all coordinates are in mm relative to the same board-centre origin used by the Gerbers. Angles are the current **footprint/CPL angles**, not independently calibrated JLC angles. `release/placement-review.json` records the actual pad coordinates/nets and binds this review to the exact circuit and CPL SHA-256 hashes.

| Ref / JLC part | CPL angle | Required assembled orientation / board landmarks |
|---|---:|---|
| U1 ESP32-S3-WROOM-1-N16R8 / C2913202 | 0° | Antenna north. Pin 1 GND northwest at (−4.2500, 9.5450); pin 2 VDD_IO immediately south. Pin 40 GND northeast. |
| J1 TYPE-C-31-M-12 / C165948 | 270° | USB mouth west/left, SMT signal row east. CC1 at (−18.6760, 4.2499), CC2 at (−18.6760, 1.2499). Use connector pad names, not the imported shell-tab `pin1`, as the orientation reference. |
| J2 AFC01-S24FCA-00 / C262669 | 90° | Mouth east/right, flex contacts down. Pin 1 south at (21.1999, −7.2498), pin 24 north at (21.1999, 4.2501). Signal row west of the body; mounting tabs east. |
| D1 SMF5.0A / C193402 | 0° | Pin 1 cathode/bar west at (−22.6350, 9.7000), connected to VBUS_5V. Pin 2 anode east at (−19.3650, 9.7000), GND. Explicit supplier pin numbering is enforced by the hardware contract. |
| LED1 KT-0603R / C2286 | 0° | Cathode west at (−13.4501, −13.8000), GND. Anode east at (−11.9499, −13.8000), driven through R13. Confirm the actual supplier polarity mark against these nets. |
| U2 USBLC6-2SC6 / C2687116 | 270° | Pin 1 northwest at (−16.8491, 0.9500). Pin 2 GND west-centre, pin 5 VBUS east-centre. |
| U3 TLV62569DBVR / C141836 | 90° | Pin 1 EN northeast at (−10.0500, −0.1999); pin 2 GND north-centre; pin 3 SW northwest; pin 4 VIN southwest; pin 5 FB southeast. |
| U4 XC6206P282MR / C347374 | 0° | Pin 1 VSS southeast at (−18.8987, −7.4500); pin 2 VOUT northeast; single pin 3 VIN west. |
| U5 SGM2059-ADJXN5G/TR / C5152783 | 0° | Pin 1 IN southeast at (−16.8999, −11.6498); pin 2 GND east-centre; pin 3 EN northeast; pin 4 FB northwest; pin 5 OUT southwest. |

The regulator/module pin arrangements were compared with the manufacturer top-view drawings: [ESP32, figure 3-1](https://documentation.espressif.com/esp32-s3-wroom-1_wroom-1u_datasheet_en.pdf), [TLV62569, DBV pin diagram](https://www.ti.com/lit/ds/symlink/tlv62569.pdf), [XC6206, SOT-23 top view](https://product.torexsemi.com/system/files/series/xc6206.pdf), [SGM2059, SOT-23-5 pin configuration](https://www.sg-micro.com/rect/assets/c90e4805-a9a9-4001-be72-fb96737d867e/SGM2059.pdf), and [USBLC6-2 pinout](https://www.st.com/resource/en/datasheet/usblc6-2.pdf). The exact [AFC01 drawing](https://datasheet.lcsc.com/datasheet/pdf/97e3ba016a78286ffa6cfbc591e2beb6.pdf) establishes the board connector orientation. The generated copper/net connections agree with the hardware contract. These comparisons do not establish JLC's feeder/model zero angle.

## Pending JLC preview

The J2 row above describes the existing board footprint, not a qualified camera-to-pad mapping. The numbered M0031 tail photograph raises a possible reversal after accounting for the exposed face and insertion direction; see [camera mating review](camera-mating.md). A correctly placed J2 model in JLC's preview cannot by itself close that separate mapping/fit hold.

Upload the current `museview-v1-gerbers.zip`, `jlc-bom.csv` and `jlc-cpl.csv` from the same release. Select top assembly only, retain all 49 fitted parts and exclude the 11 bare test pads and external M0031 camera. Verify exact C-numbers and available assembly quantities. Compare every critical part above to the actual supplier model/mark and land pattern, including centres on asymmetric USB/FPC/module bodies. Check the rest of the placements for offset or 90° errors as well. Record any supplier-specific correction and regenerate the CPL/report before release; do not rotate the board footprint or reroute copper to compensate for a supplier angle convention.

[JLC's own FAQ](https://jlcpcb.com/help/article/pcb-assembly-faqs-part-2) explains that CAD and supplier zero-angle conventions can differ and that its red dot is not necessarily electrical pin 1. Use actual package features/polarity and the pin/net landmarks above, not a dot alone. Do not silently add a generic 90°/180° offset. The native exporter reports missing supplier pin-1-location metadata, so none of these CPL angles is claimed supplier-approved.

## Scope retained

USB-C stays 5 V only, VDD_IO 3.192 V, CAM_2V8 2.8 V and CAM_1V3 1.296 V. All fitted components remain on top. This review changes documentation, stock timestamps and release evidence only; it does not change parts, electrical connections, layout, routes or 3D geometry. Prototype rail and functional measurements are performed after assembly as described in `bring-up.md`.

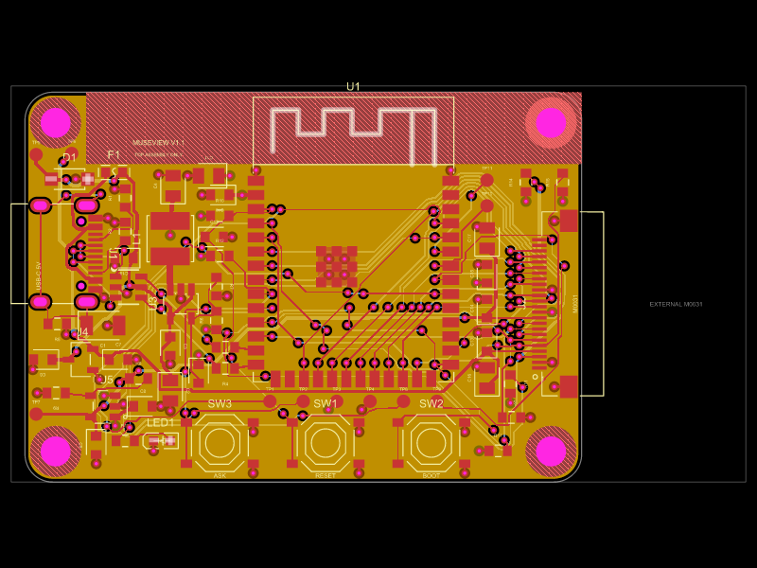
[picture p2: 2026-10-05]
release/pcb-top.png

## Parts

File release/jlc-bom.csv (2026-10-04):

Comment | Designator | Footprint | LCSC Part #
C1206X472K202T | C1 | 1206 | C106076
0805B475K100NT | C2,C16,C17 | 0805 | C2857993
GRM21BR71A106KE51L | C4,C11 | 0805 | C86038
0603CG6R8C500NT | C5 | 0603 | C1679
CC0603KRX7R6BB105 | C6,C7,C8,C9,C12 | 0603 | C113807
CC0603KRX7R9BB104 | C18,C3,C10,C13,C14,C15 | 0603 | C14663
SMF5.0A | D1 | SOD-123FL | C193402
BSMD0603-075-6V | F1 | 0603 | C914092
TYPE-C-31-M-12 | J1 | SMD | C165948
AFC01-S24FCA-00 | J2 | SMD,P=0.5mm,卧贴 | C262669
WPN4020H2R2MT | L1 | SMD,4x4mm | C98361
KT-0603R | LED1 | 0603 | C2286
0603WAF5101T5E | R1,R2 | 0603 | C23186
0603WAF330JT5E | R3,R4 | 0603 | C23140
0603WAF1004T5E | R5 | 0603 | C22935
RT0603BRD07432KL | R6 | 0603 | C861402
ARG03BTC1003 | R7 | 0603 | C335088
0603WAF2552T5E | R8 | 0603 | C22920
FRC0603F4022TS | R9 | 0603 | C2933218
0603WAF1002T5E | R10,R11,R12,R16,R17 | 0603 | C25804
0603WAF1001T5E | R13 | 0603 | C21190
0603WAF4701T5E | R14,R15 | 0603 | C23162
TS-1187A-B-A-B | SW1,SW2,SW3 | SMD-4P,5.1x5.1mm | C318884
ESP32-S3-WROOM-1-N16R8 | U1 | SMD,25.5x18mm | C2913202
USBLC6-2SC6 | U2 | SOT-23-6 | C2687116
TLV62569DBVR | U3 | SOT-23-5 | C141836
XC6206P282MR | U4 | SOT-23 | C347374
SGM2059-ADJXN5G/TR | U5 | SOT-23-5 | C5152783

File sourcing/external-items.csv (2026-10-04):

item | quantity | assembly | status
Arducam M0031 OV2640 24-pin DVP camera | 1 | hand fit after PCBA | external purchase; JLC availability not claimed
Regulated USB-C 5 V source at least 1 A | 1 | external | bring-up supply
USB data cable | 1 | external | must carry USB2 data
M2.5 mounting hardware and enclosure | 1 set | mechanical | verify head and antenna clearance

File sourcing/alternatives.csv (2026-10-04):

primary_lcsc | alternate_lcsc | value | package | qualification | status
C25804 | C2906982 | 10k 1% | 0603 | Same nominal value tolerance and package; verify height and JLC placement | stock verified; not substituted
C25804 | C98220 | 10k 1% | 0603 | Same nominal value tolerance and package; verify height and JLC placement | stock verified; not substituted
C335088 | C326758 | 100k 0.1% | 0603 | Must retain 0.1% tolerance for common IO rail | stock verified; not substituted

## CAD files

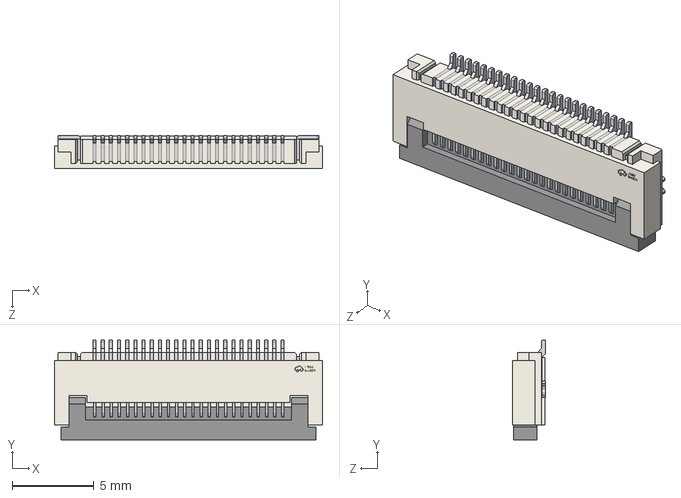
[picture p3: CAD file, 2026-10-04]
imports/AFC01_S24FCA_00/AFC01_S24FCA_00.step
16.4 x 6.10 x 2.01 mm

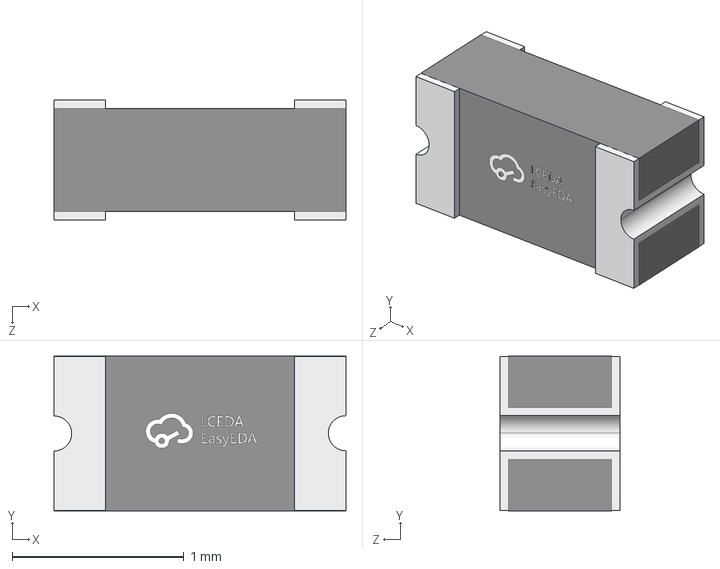
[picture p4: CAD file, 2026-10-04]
imports/BSMD0603_075_6V/BSMD0603_075_6V.step
1.70 x 0.9 x 0.7 mm

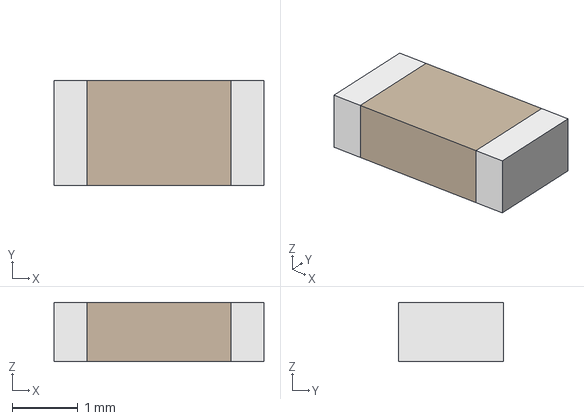
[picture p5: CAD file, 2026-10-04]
imports/builtin/cap1206.step
3.20 x 1.60 x 0.9 mm

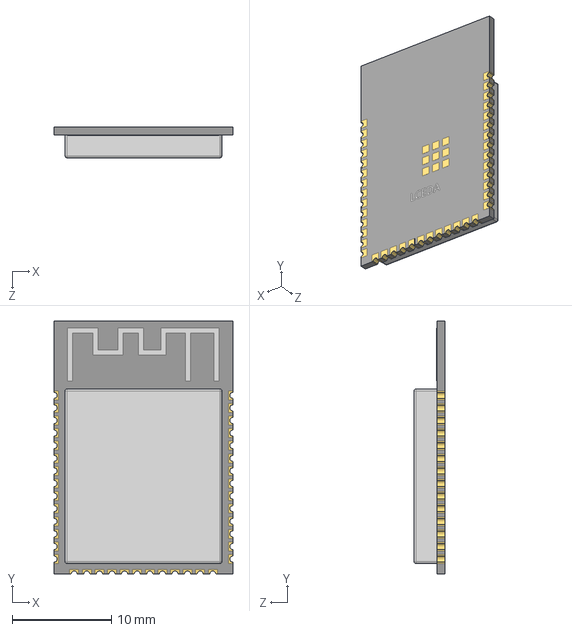
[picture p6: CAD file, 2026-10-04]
imports/ESP32_S3_WROOM_1_N16R8/ESP32_S3_WROOM_1_N16R8.step
18.0 x 25.5 x 3.11 mm

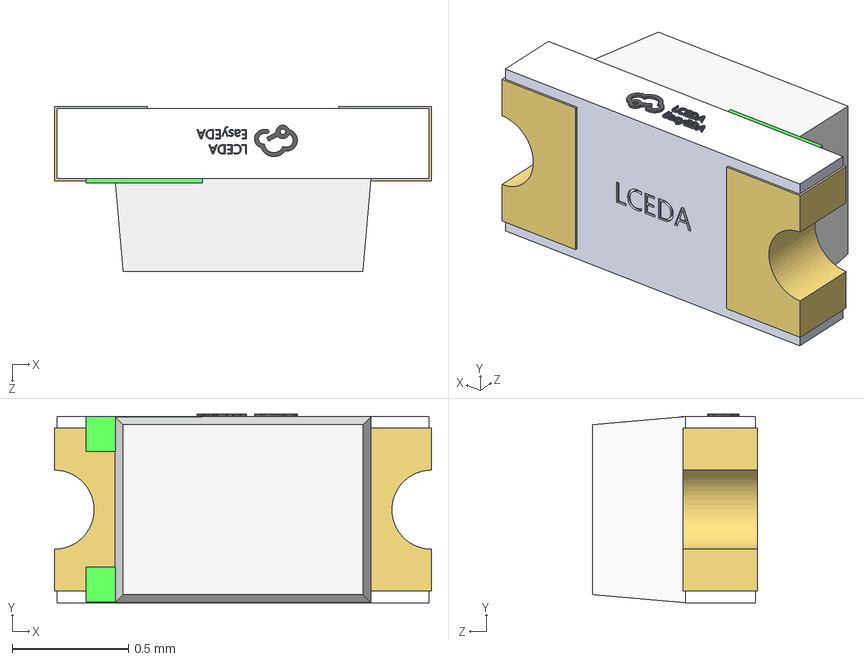
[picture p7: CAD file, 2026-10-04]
imports/KT_0603R/KT_0603R.step
1.62 x 0.81 x 0.71 mm

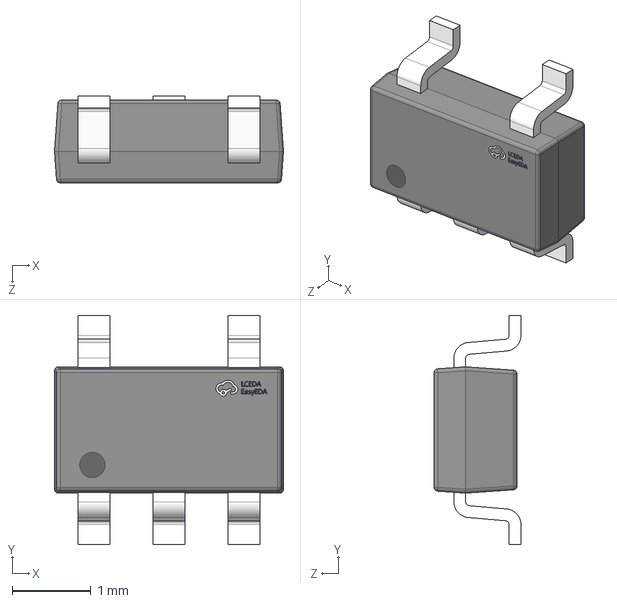
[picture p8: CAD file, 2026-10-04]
imports/SGM2059_ADJXN5G_TR/SGM2059_ADJXN5G_TR.step
2.90 x 2.90 x 1.10 mm

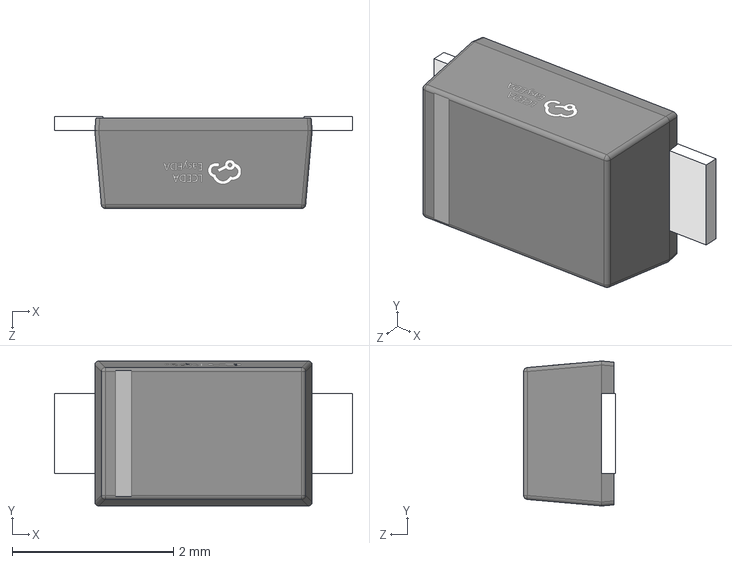
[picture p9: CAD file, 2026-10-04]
imports/SMF5_0A/SMF5_0A.step
3.70 x 1.80 x 1.14 mm

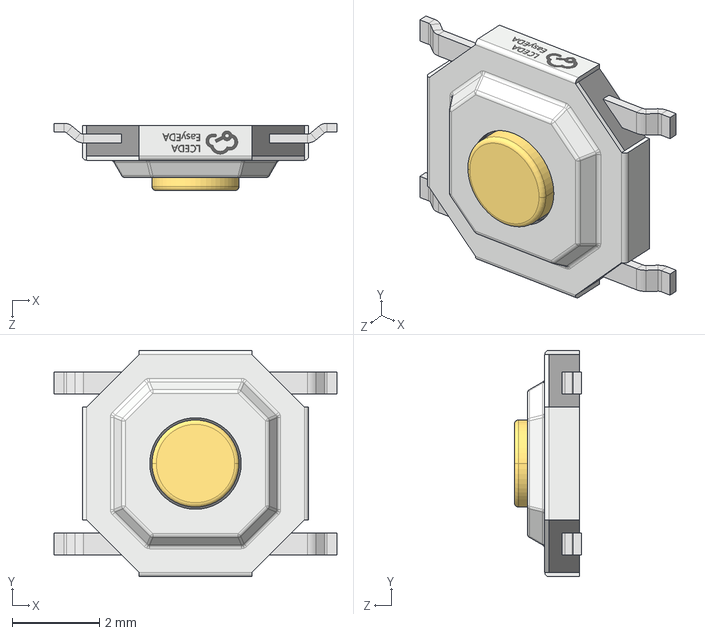
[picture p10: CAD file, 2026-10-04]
imports/TS_1187A_B_A_B/TS_1187A_B_A_B.step
6.50 x 5.20 x 1.55 mm

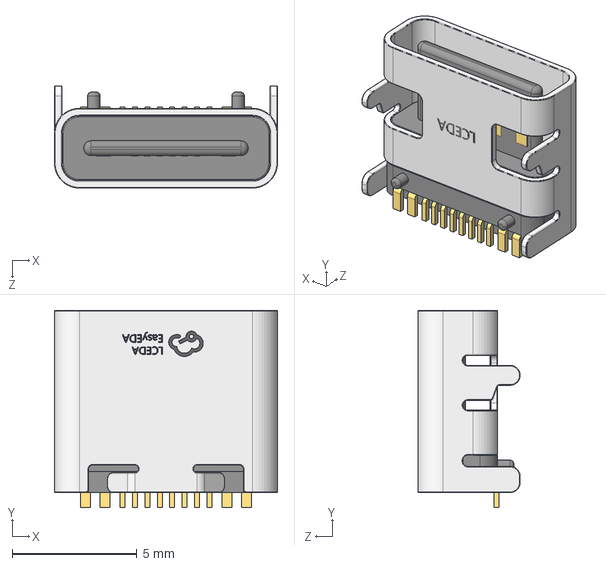
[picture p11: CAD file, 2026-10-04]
imports/TYPE_C_31_M_12/TYPE_C_31_M_12.step
8.94 x 7.90 x 4.10 mm

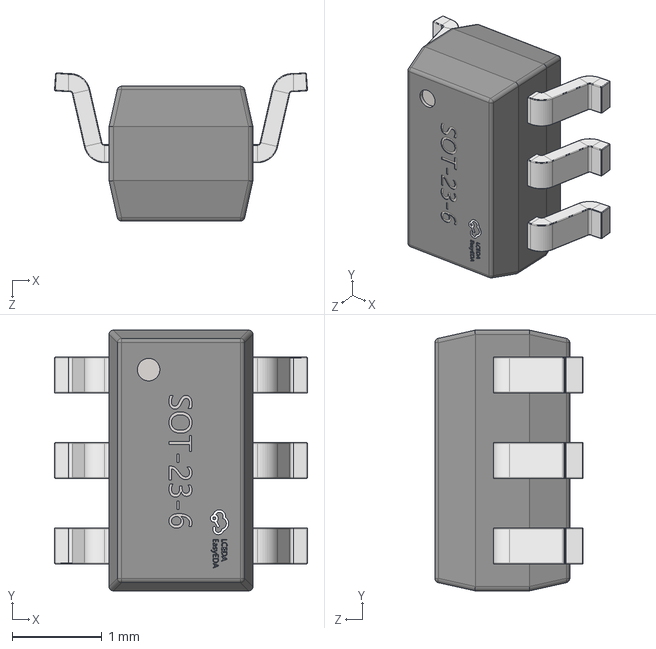
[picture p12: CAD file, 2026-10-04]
imports/USBLC6_2SC6/USBLC6_2SC6.step
2.81 x 2.90 x 1.65 mm

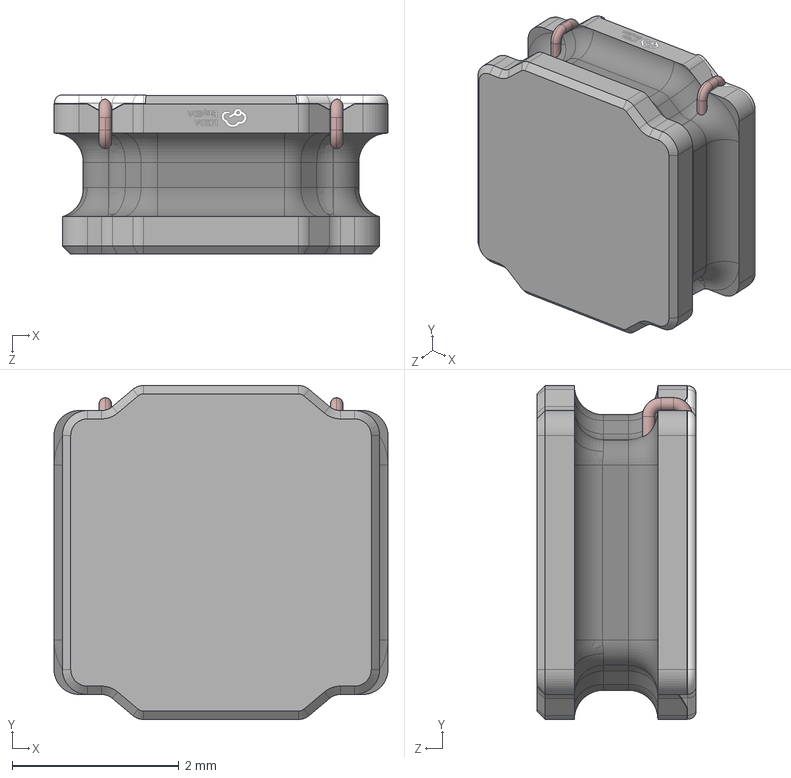
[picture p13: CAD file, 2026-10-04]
imports/WPN4020H2R2MT/WPN4020H2R2MT.step
4.00 x 4.00 x 1.91 mm

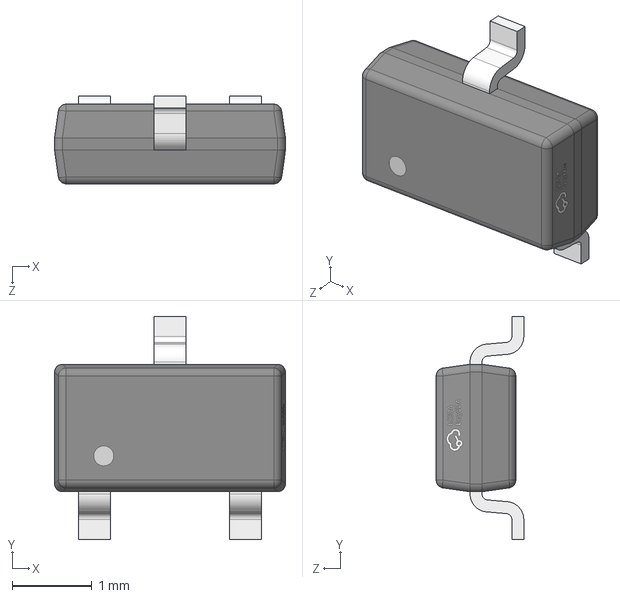
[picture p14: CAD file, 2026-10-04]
imports/XC6206P282MR/XC6206P282MR.step
2.90 x 2.80 x 1.10 mm

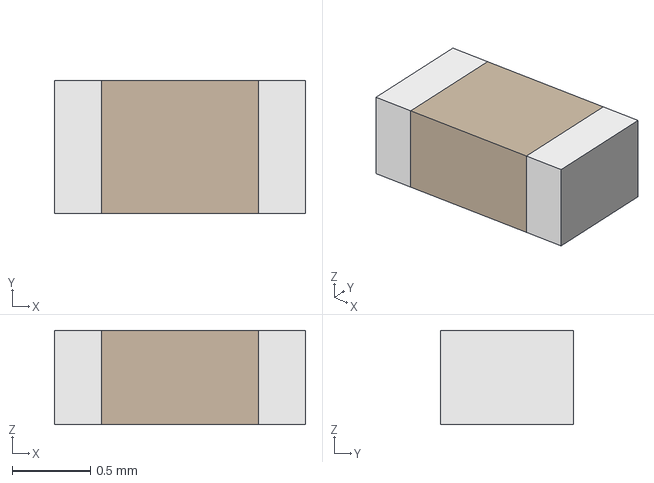
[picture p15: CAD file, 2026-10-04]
imports/builtin/cap0603.step
1.60 x 0.85 x 0.6 mm

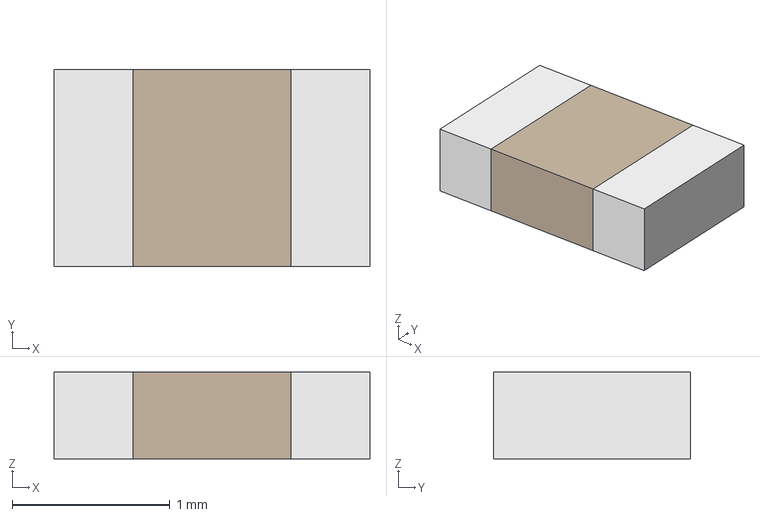
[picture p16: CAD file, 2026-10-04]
imports/builtin/cap0805.step
2.00 x 1.25 x 0.55 mm

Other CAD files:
imports/builtin/res0603.step
imports/TLV62569DBVR/TLV62569DBVR.step
imports/AFC01_S24FCA_00/AFC01_S24FCA_00.obj
imports/BSMD0603_075_6V/BSMD0603_075_6V.obj
imports/ESP32_S3_WROOM_1_N16R8/ESP32_S3_WROOM_1_N16R8.obj
imports/KT_0603R/KT_0603R.obj
imports/SGM2059_ADJXN5G_TR/SGM2059_ADJXN5G_TR.obj
imports/SMF5_0A/SMF5_0A.obj
imports/TLV62569DBVR/TLV62569DBVR.obj
imports/TS_1187A_B_A_B/TS_1187A_B_A_B.obj
imports/TYPE_C_31_M_12/TYPE_C_31_M_12.obj
imports/USBLC6_2SC6/USBLC6_2SC6.obj
imports/WPN4020H2R2MT/WPN4020H2R2MT.obj
imports/XC6206P282MR/XC6206P282MR.obj

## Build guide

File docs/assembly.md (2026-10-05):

# Assembly

V1.1 is 50 × 35 mm, with USB left, camera connector right and ASK / RESET / BOOT in the south-edge row. All 49 fitted components are on the top side. Bottom assembly is prohibited and checked for every fitted component and SMT pad. Probe pads are bare copper features and must not enter the assembly BOM. BOM and placement CSVs are generated from the final circuit JSON, with exact JLC numbers. Quantities must be regenerated after circuit changes. Copper, drill and JLC centroid coordinates share the board-center origin; negative coordinates are intentional. Do not offset the CPL independently of the Gerbers. Rotation is the tscircuit footprint rotation, so check every polarized part in the JLC placement preview.

- U1: ESP32-S3-WROOM-1-N16R8, not MINI/1U or another memory variant. PCB antenna points toward the north edge. Do not place copper, metal fasteners, battery or enclosure metal in the marked RF keepout. Exposed ground lands need the specified solder paste and solder-mask-covered ground island.
- J1: TYPE-C-31-M-12, facing west. Receptacle mouth intentionally overhangs the board. Verify plated mounting slots and locating holes in the fabrication preview. The shell tabs enter plated slots from the top; their underside annuli are not bottom-mounted components. Request top-side processing for these tabs. The release exporter deliberately leaves B_Paste empty (the pinned generic exporter otherwise adds shell-tab paste on both sides); copper, mask and drills are preserved.
- J2: AFC01-S24FCA-00, 24 contacts at 0.5 mm pitch, bottom contact, 0.30 mm nominal flex. The connector opens toward the east/right board edge; pad 1 is at the south/bottom end of the contact row. “Bottom contact” describes the flex mating contacts, not a bottom-side PCB assembly. Contacts on the mating flex face the PCB; verify the physical M0031 tail's pin 1 and insertion geometry before energizing. Do not force or hot-plug the latch. See [camera mating review](camera-mating.md) for the manufacturer evidence and remaining exact-flex qualification hold.
- D1: SMF5.0A is unidirectional. Cathode is the west/negative-X pad and connects to protected 5 V; anode is ground. Native diode pin aliases are used; physical footprint pad polarity is explicitly preserved.
- LED1: imported KT-0603R polarity; inspect the anode from GPIO17 through R13 and cathode to GND.
- U3/U4/U5: compare pin-1 and package rotations with manufacturer drawings, not only rendered bodies. The 3D asset is a visualization and is not a substitute for a land-pattern drawing. The current angles and actual board pin/polarity landmarks for all critical parts are recorded in [placement-review.md](placement-review.md); JLC preview approval remains pending.
- R6/R7: 432 kΩ and 100 kΩ, **0.1%**, mandatory. R8: 25.5 kΩ, 1%, C22920; R9: 40.2 kΩ, 1%, C2933218. The previous 20.5 kΩ R8 must not be fitted.

All signal and power vias use 0.30 mm plated through drills and 0.60 mm pads across the four-layer stack. No blind or buried vias are specified. See `routing.md` for the decision to retain the active ground and supply planes.

Four corner holes are 2.7 mm nonplated, intended for M2.5 hardware. Use nylon fasteners/standoffs, especially the northeast hole inside the antenna exclusion; no metal screw or enclosure insert is permitted in that RF region. Check screw-head/enclosure clearances. The external camera needs mechanical support; its outline is an assembly note outside the PCB, not fabricated board area.

Imports were downloaded using `tsci import C<number> --jlcpcb --download --use-exact-footprint`. Primitive selection, pin attributes and connectivity aliases were reviewed after import. Standard passives use native tscircuit footprints with explicit supplier identities. R8 uses the native 0603 footprint with the verified C22920 identity; the older 0402 25.5 kΩ candidate is not used.

External items (not JLC assembly): Arducam M0031, rated 5 V USB supply/cable, M2.5 hardware/enclosure. No alternate camera module is approved without rechecking pinout, flex orientation, rail ranges and GPIO timing.

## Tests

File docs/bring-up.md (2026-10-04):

# Bring-up

Use a prototype first. Automated CAD checks cannot confirm soldering, rail startup or camera behavior.

1. Inspect J1/J2 alignment, regulator and diode orientation, bridge-free FPC lands and the module ground pad. With power off, check for hard shorts from 5 V, VDD_IO, CAM_2V8 and CAM_1V3 to GND. Capacitor charging is not a DC short.
2. Leave the camera unplugged. Apply current-limited 5.0 V with a conservative initial limit; if the ESP repeatedly brownouts, inspect rather than assuming normal startup. Verify TP5 near the input voltage, TP3 nominal 3.192 V, TP6 nominal 2.8 V and TP7 nominal 1.296 V. Require TP7/CAM_1V3 to stay within 1.24–1.36 V during steady operation, including ripple and measurement uncertainty; capture startup/unplug waveforms separately against sequencing requirements. Reject a camera core voltage outside 1.24–1.36 V or shared I/O above 3.3 V.
3. Verify EN rises after supply startup and RESET pulls it low. Hold BOOT, tap RESET, release BOOT; verify native USB ROM enumeration. Test both Type-C plug orientations. UART0 pads are 3.2 V logic; never connect an RS-232 level interface.
4. Build and flash `firmware/`. Confirm 16 MB flash and 8 MB octal PSRAM are detected. ASK is active low GPIO16, LED active high GPIO17. JTAG test pads correspond to GPIO39–42; native USB Serial/JTAG is also available.
5. Record the exact-flex checks in `camera-mating.md` before first-prototype release. Remove power before fitting the camera. Verify exact M0031 flex orientation and pin-1 alignment, close the latch, support the camera mechanically. Do not use a similarly shaped module on appearance alone.
6. With oscilloscope probes at the camera connector, capture all three rails, RESET and PWDN during power-up and unplug/replug. Check no damaging back-power or input excursion occurs. Verify camera identity through SCCB and one JPEG capture before sustained operation.
7. Exercise ASK, repeat capture, Wi-Fi transmission and reconnect. Measure supply current, minimum MCU voltage, rail ripple, regulator temperature and USB behavior with the intended cable/source. Complete the release-check worksheet with measurements and serial numbers.

If firmware cannot detect the camera, first check flex orientation, RESET/PWDN, XCLK, the 2.8 V analog rail and CAM_1V3 (1.296 V nominal), then SDA/SCL. Do not adjust the core outside the 1.24–1.36 V acceptance band to mask a detection failure.

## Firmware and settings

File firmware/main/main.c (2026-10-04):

#include <stdlib.h>
#include <assert.h>
#include <string.h>
#include <stdio.h>
#include "freertos/FreeRTOS.h"
#include "freertos/task.h"
#include "freertos/semphr.h"
#include "driver/gpio.h"
#include "esp_camera.h"
#include "esp_event.h"
#include "esp_http_server.h"
#include "esp_log.h"
#include "esp_mac.h"
#include "esp_netif.h"
#include "esp_psram.h"
#include "esp_wifi.h"
#include "nvs_flash.h"
#include "board_pins.h"

static const char *TAG = "MuseView";
static SemaphoreHandle_t camera_lock;
static uint8_t *last_jpeg;
static size_t last_size;
static unsigned capture_count;
static bool camera_ready;

// Caller owns camera_lock. Driver buffers never escape this function.
static esp_err_t capture_locked(void) {
    if (!camera_ready) return ESP_ERR_INVALID_STATE;
    gpio_set_level(MV_LED, 1);
    camera_fb_t *fb = esp_camera_fb_get();
    esp_err_t result = ESP_FAIL;
    if (fb && fb->format == PIXFORMAT_JPEG && fb->len <= 1024 * 1024) {
        uint8_t *copy = malloc(fb->len);
        if (copy) {
            memcpy(copy, fb->buf, fb->len);
            free(last_jpeg);
            last_jpeg = copy;
            last_size = fb->len;
            ++capture_count;
            result = ESP_OK;
            ESP_LOGI(TAG, "JPEG %u: %u bytes", capture_count, (unsigned)last_size);
        } else result = ESP_ERR_NO_MEM;
    }
    if (fb) esp_camera_fb_return(fb);
    gpio_set_level(MV_LED, 0);
    return result;
}
static esp_err_t image_handler(httpd_req_t *req) {
    if (xSemaphoreTake(camera_lock, pdMS_TO_TICKS(5000)) != pdTRUE)
        return httpd_resp_send_err(req, HTTPD_500_INTERNAL_SERVER_ERROR, "Camera busy");
    bool fresh = strcmp(req->uri, "/capture.jpg") == 0;
    esp_err_t err = fresh ? capture_locked() : (last_jpeg ? ESP_OK : ESP_ERR_NOT_FOUND);
    if (err == ESP_OK) {
        httpd_resp_set_type(req, "image/jpeg");
        httpd_resp_set_hdr(req, "Cache-Control", "no-store");
        err = httpd_resp_send(req, (const char *)last_jpeg, last_size);
    } else err = httpd_resp_send_err(req, HTTPD_500_INTERNAL_SERVER_ERROR, "No JPEG; check camera and serial log");
    xSemaphoreGive(camera_lock);
    return err;
}
static esp_err_t root_handler(httpd_req_t *req) {
    const char page[] = "<!doctype html><html lang=en><meta name=viewport content='width=device-width,initial-scale=1'>"
      "<title>MuseView</title><style>body{font:18px system-ui;max-width:700px;margin:40px auto;padding:20px;background:#10251f;color:#f6f3e8}"
      "button{padding:14px 22px;font:inherit;margin-right:8px}img{display:block;max-width:100%;margin-top:24px}small{display:block;margin-top:24px}</style>"
      "<h1>MuseView</h1><p>Local camera bring-up</p><button onclick=show('/capture.jpg')>Capture</button>"
      "<button onclick=show('/last.jpg')>Last ASK capture</button><p id=status>Ready</p><img id=photo alt='Captured image'>"
      "<small>Images stay on this local device. ASK also takes a snapshot.</small><script>const statusEl=document.getElementById('status'),photoEl=document.getElementById('photo');async function show(url){"
      "statusEl.textContent='Capturing…';try{let r=await fetch(url,{cache:'no-store'});if(!r.ok)throw Error(await r.text());"
      "let old=photoEl.src;photoEl.src=URL.createObjectURL(await r.blob());if(old.startsWith('blob:'))URL.revokeObjectURL(old);"
      "statusEl.textContent='JPEG ready'}catch(e){statusEl.textContent=e.message}}</script></html>";
    httpd_resp_set_type(req, "text/html");
    return httpd_resp_send(req, page, HTTPD_RESP_USE_STRLEN);
}
static void ask_task(void *arg) {
    (void)arg;
    int stable = 1, previous = 1, count = 0;
    for (;;) {
        int value = gpio_get_level(MV_ASK);
        count = value == previous ? count + 1 : 0;
        if (count > 3) count = 3;
        if (count == 3 && value != stable) {
            stable = value;
            if (!stable && xSemaphoreTake(camera_lock, pdMS_TO_TICKS(5000)) == pdTRUE) {
                if (capture_locked() != ESP_OK) ESP_LOGE(TAG, "ASK capture failed");
                xSemaphoreGive(camera_lock);
            }
        }
        previous = value;
        vTaskDelay(pdMS_TO_TICKS(10));
    }
}
void app_main(void) {
    ESP_LOGI(TAG,"CAM_1V3 hardware target %d mV; verify TP7 %d–%d mV externally (not measured by firmware)",
        MV_CAMERA_CORE_TARGET_MV, MV_CAMERA_CORE_MIN_MV, MV_CAMERA_CORE_MAX_MV);
    camera_lock = xSemaphoreCreateMutex();
    assert(camera_lock);
    gpio_config_t output = {.pin_bit_mask=(1ULL<<MV_LED)|(1ULL<<MV_RESET)|(1ULL<<MV_PWDN), .mode=GPIO_MODE_OUTPUT};
    ESP_ERROR_CHECK(gpio_config(&output));
    gpio_set_level(MV_LED,0); gpio_set_level(MV_RESET,0); gpio_set_level(MV_PWDN,1);
    gpio_config_t input = {.pin_bit_mask=1ULL<<MV_ASK,.mode=GPIO_MODE_INPUT,.pull_up_en=GPIO_PULLUP_ENABLE};
    ESP_ERROR_CHECK(gpio_config(&input));
    vTaskDelay(pdMS_TO_TICKS(20));
    gpio_set_level(MV_PWDN,0); vTaskDelay(pdMS_TO_TICKS(10));
    gpio_set_level(MV_RESET,1); vTaskDelay(pdMS_TO_TICKS(20));
    if (!esp_psram_is_initialized() || esp_psram_get_size() < 8*1024*1024) {
        ESP_LOGE(TAG,"Expected 8 MB octal PSRAM; check N16R8 and sdkconfig");
        return;
    }
    camera_config_t camera = {
        .pin_pwdn=MV_PWDN,.pin_reset=MV_RESET,.pin_xclk=MV_XCLK,
        .pin_sccb_sda=MV_SDA,.pin_sccb_scl=MV_SCL,
        .pin_d0=MV_D0,.pin_d1=MV_D1,.pin_d2=MV_D2,.pin_d3=MV_D3,
        .pin_d4=MV_D4,.pin_d5=MV_D5,.pin_d6=MV_D6,.pin_d7=MV_D7,
        .pin_vsync=MV_VSYNC,.pin_href=MV_HREF,.pin_pclk=MV_PCLK,
        .xclk_freq_hz=20000000,.ledc_timer=LEDC_TIMER_0,.ledc_channel=LEDC_CHANNEL_0,
        .pixel_format=PIXFORMAT_JPEG,.frame_size=FRAMESIZE_SVGA,.jpeg_quality=12,
        .fb_count=1,.fb_location=CAMERA_FB_IN_PSRAM,.grab_mode=CAMERA_GRAB_WHEN_EMPTY
    };
    esp_err_t err=esp_camera_init(&camera);
    camera_ready=err==ESP_OK;
    if (!camera_ready) ESP_LOGE(TAG,"Camera init failed: %s",esp_err_to_name(err));
    err=nvs_flash_init();
    if(err==ESP_ERR_NVS_NO_FREE_PAGES || err==ESP_ERR_NVS_NEW_VERSION_FOUND) {ESP_ERROR_CHECK(nvs_flash_erase());err=nvs_flash_init();}
    ESP_ERROR_CHECK(err); ESP_ERROR_CHECK(esp_netif_init());ESP_ERROR_CHECK(esp_event_loop_create_default());
    esp_netif_create_default_wifi_ap();
    wifi_init_config_t cfg=WIFI_INIT_CONFIG_DEFAULT(); ESP_ERROR_CHECK(esp_wifi_init(&cfg));
    uint8_t mac[6];ESP_ERROR_CHECK(esp_read_mac(mac,ESP_MAC_WIFI_SOFTAP));
    wifi_config_t wifi={.ap={.channel=1,.max_connection=2,.authmode=WIFI_AUTH_WPA2_PSK}};
    snprintf((char*)wifi.ap.ssid,sizeof(wifi.ap.ssid),"MuseView-%02X%02X%02X",mac[3],mac[4],mac[5]);
    const char *password=CONFIG_MUSEVIEW_AP_PASSWORD;
    if(strlen(password)<8 || strlen(password)>63) {ESP_LOGE(TAG,"AP password must be 8–63 characters");return;}
    memcpy(wifi.ap.password,password,strlen(password)+1);
    ESP_ERROR_CHECK(esp_wifi_set_mode(WIFI_MODE_AP));ESP_ERROR_CHECK(esp_wifi_set_config(WIFI_IF_AP,&wifi));ESP_ERROR_CHECK(esp_wifi_start());
    httpd_config_t server_cfg=HTTPD_DEFAULT_CONFIG();server_cfg.stack_size=8192;
    httpd_handle_t server;ESP_ERROR_CHECK(httpd_start(&server,&server_cfg));
    const httpd_uri_t home={.uri="/",.method=HTTP_GET,.handler=root_handler};
    const httpd_uri_t capture={.uri="/capture.jpg",.method=HTTP_GET,.handler=image_handler};
    const httpd_uri_t last={.uri="/last.jpg",.method=HTTP_GET,.handler=image_handler};
    ESP_ERROR_CHECK(httpd_register_uri_handler(server,&home));ESP_ERROR_CHECK(httpd_register_uri_handler(server,&capture));ESP_ERROR_CHECK(httpd_register_uri_handler(server,&last));
    if(xTaskCreate(ask_task,"ask",4096,NULL,5,NULL)!=pdPASS) ESP_LOGE(TAG,"Could not start ASK task");
    ESP_LOGI(TAG,"Join %s then open http://192.168.4.1/",wifi.ap.ssid);
}

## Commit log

2026-10-04 Implement MuseView USB5V schematic, JLC sourcing and prototype checks
    [AFC01_S24FCA_00.obj, AFC01_S24FCA_00.step, BSMD0603_075_6V.obj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]
2026-10-04 Complete routed USB 5V camera PCB, verified CAD exports and regression checks
    [AFC01_S24FCA_00.step, BSMD0603_075_6V.step, ESP32_S3_WROOM_1_N16R8.step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]
2026-10-04 Redesign MuseView as a 50x35 mm top-assembly board
    [jlc-cpl.csv]
2026-10-04 Correct M0031 core supply to 1.296 V and qualify camera interface
    [alternatives.csv, bom-with-stock.csv, jlc-bom.csv]
2026-10-04 Record first-prototype mating and placement blockers with refreshed release evidence
    [bom-with-stock.csv]
2026-10-04 Document exact camera connector tolerances and pin-mapping hold
2026-10-05 Fix all schematic style findings and enforce zero-issue analysis
2026-10-05 Package assembled STEP to avoid cloud sandbox RPC size limit
2026-10-05 Explain MuseView overview and camera capture workflow
2026-10-05 Apply corrected USB-C CAD origin across preview and release models
2026-10-05 Keep engineering documentation focused on board behavior
2026-10-05 Embed portable TVS symbol and verify schematic rendering
2026-10-05 Increase via drills to 0.30 mm and use standard USB-C schematic
2026-10-05 Set numeric via minima to 0.30 mm hole and 0.45 mm pad
